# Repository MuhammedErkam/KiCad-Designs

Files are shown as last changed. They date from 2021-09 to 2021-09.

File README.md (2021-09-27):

# KiCad-Designs
My KiCad PCB Designs

This PCB is 4 layer PCB.
Signal - GND - POWER - Signal

##### MCU - STM32F103C8T6
##### RF Module - Ai Thinker Lora Ra-02 (SX1278)
##### IMU Sensor - MPU6050
##### TEMP-PRESS Sesnor - BMP280

##### This system works with USB Micro-B
Also Micro-B connector stands for USART with CH340E

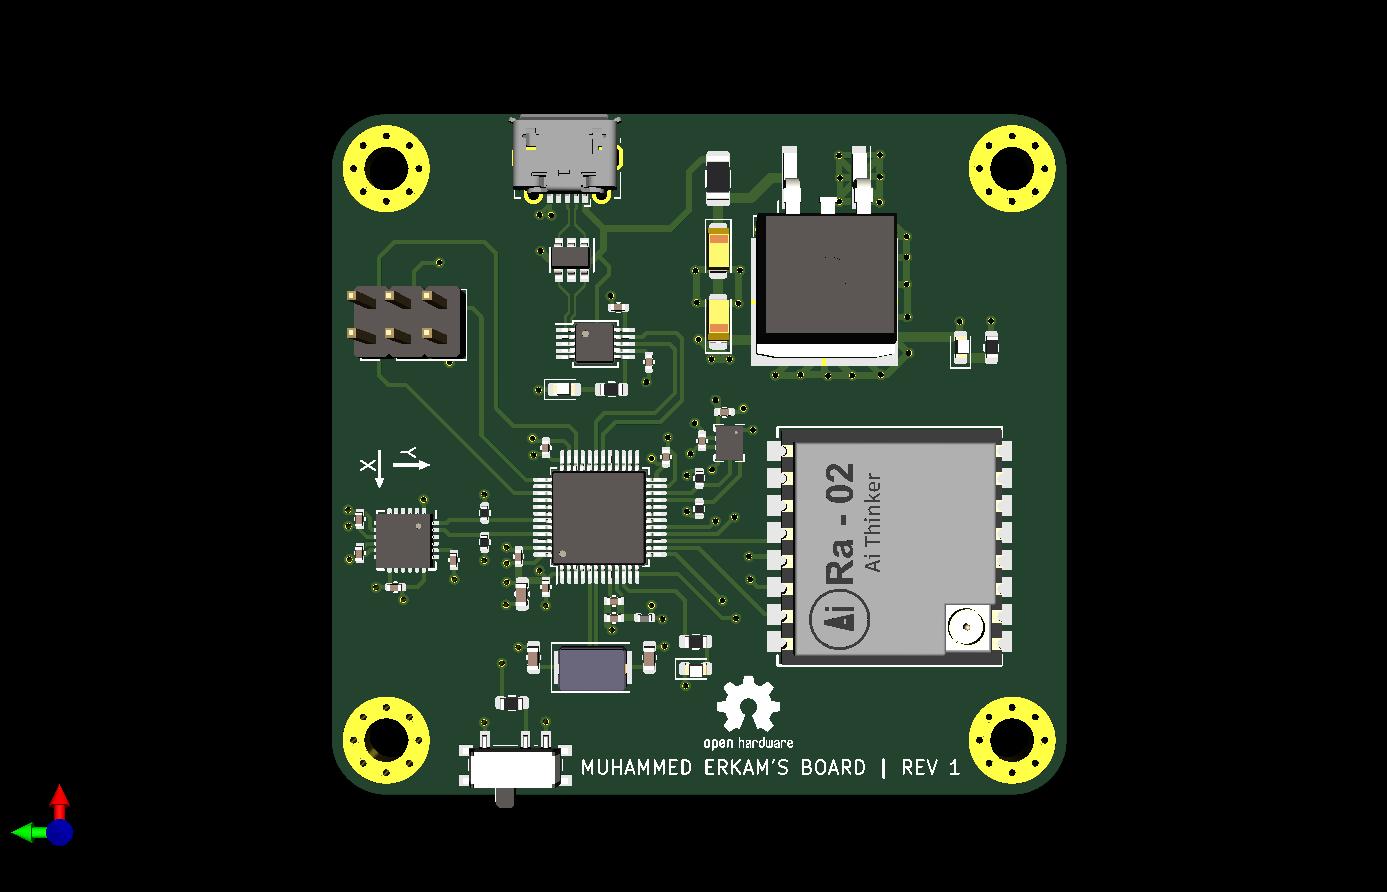
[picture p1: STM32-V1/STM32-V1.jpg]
PCB Photo


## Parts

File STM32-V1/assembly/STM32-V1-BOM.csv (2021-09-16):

Comment | Designator | Footprint | LCSC
10n | C10 | Capacitor_SMD:C_0402_1005Metric
2n2 | C15 | Capacitor_SMD:C_0402_1005Metric
30p | C16,C17 | Capacitor_SMD:C_0603_1608Metric
10u | C1,C2 | Capacitor_Tantalum_SMD:CP_EIA-3216-18_Kemet-A
4u7 | C3 | Capacitor_SMD:C_0603_1608Metric
100n | C4,C5,C6,C7,C11,C12,C13,C14,C18,C19 | Capacitor_SMD:C_0402_1005Metric
1u | C8 | Capacitor_SMD:C_0402_1005Metric
10u | C9 | Capacitor_SMD:C_0402_1005Metric
RED | D1,D3 | LED_SMD:LED_0603_1608Metric
BLUE | D2 | LED_SMD:LED_0603_1608Metric
JK-nSMD150-SF | F1 | Fuse:Fuse_1206_3216Metric
MountingHole_Pad | H1,H2,H3,H4 | MountingHole:MountingHole_3.2mm_M3_Pad_Via
USB_B_Micro | J1 | Connector_USB:USB_Micro-B_Molex-105017-0001
Conn_02x03_Odd_Even | J2 | Connector_PinHeader_2.54mm:PinHeader_2x03_P2.54mm_Vertical
27n | L1 | Inductor_SMD:L_0402_1005Metric
10k | R2 | Resistor_SMD:R_0603_1608Metric
1.5k | R3 | Resistor_SMD:R_0603_1608Metric
2k2 | R4,R5,R7,R8 | Resistor_SMD:R_0402_1005Metric
1k | R1,R6 | Resistor_SMD:R_0603_1608Metric
SW_SPDT | SW1 | Button_Switch_SMD:SW_SPDT_PCM12
LD1086D2T33TR | U1 | Package_TO_SOT_SMD:TO-263-2
USBLC6-2SC6 | U2 | Package_TO_SOT_SMD:SOT-23-6
BMP280 | U3 | Package_LGA:Bosch_LGA-8_2x2.5mm_P0.65mm_ClockwisePinNumbering
Ai-Thinker-Ra-02 | U4 | RF_Module:Ai-Thinker-Ra-02-LoRa
MPU-6050 | U5 | Sensor_Motion:InvenSense_QFN-24_4x4mm_P0.5mm
STM32F103C8Tx | U6 | Package_QFP:LQFP-48_7x7mm_P0.5mm
CH340E | U7 | Package_SO:MSOP-10_3x3mm_P0.5mm
Crystal | Y1 | Crystal:Crystal_SMD_5032-2Pin_5.0x3.2mm

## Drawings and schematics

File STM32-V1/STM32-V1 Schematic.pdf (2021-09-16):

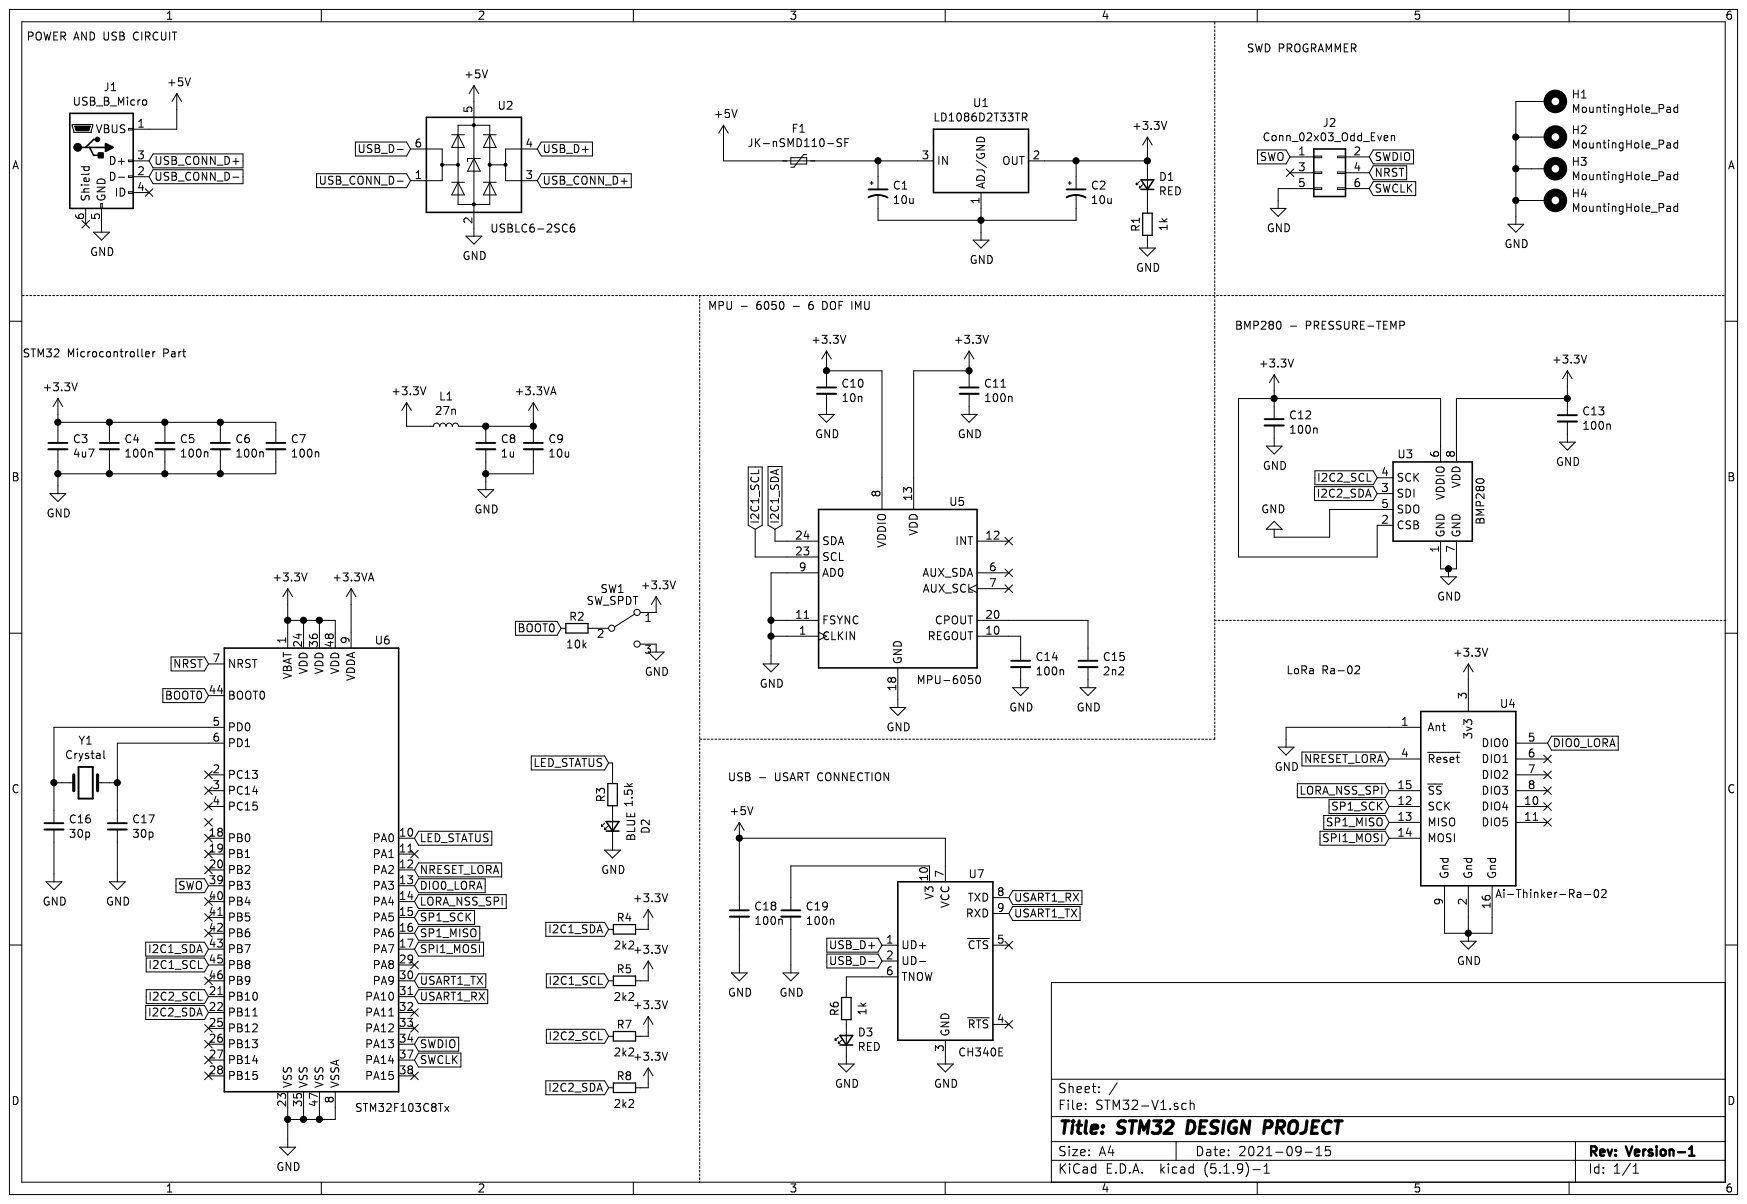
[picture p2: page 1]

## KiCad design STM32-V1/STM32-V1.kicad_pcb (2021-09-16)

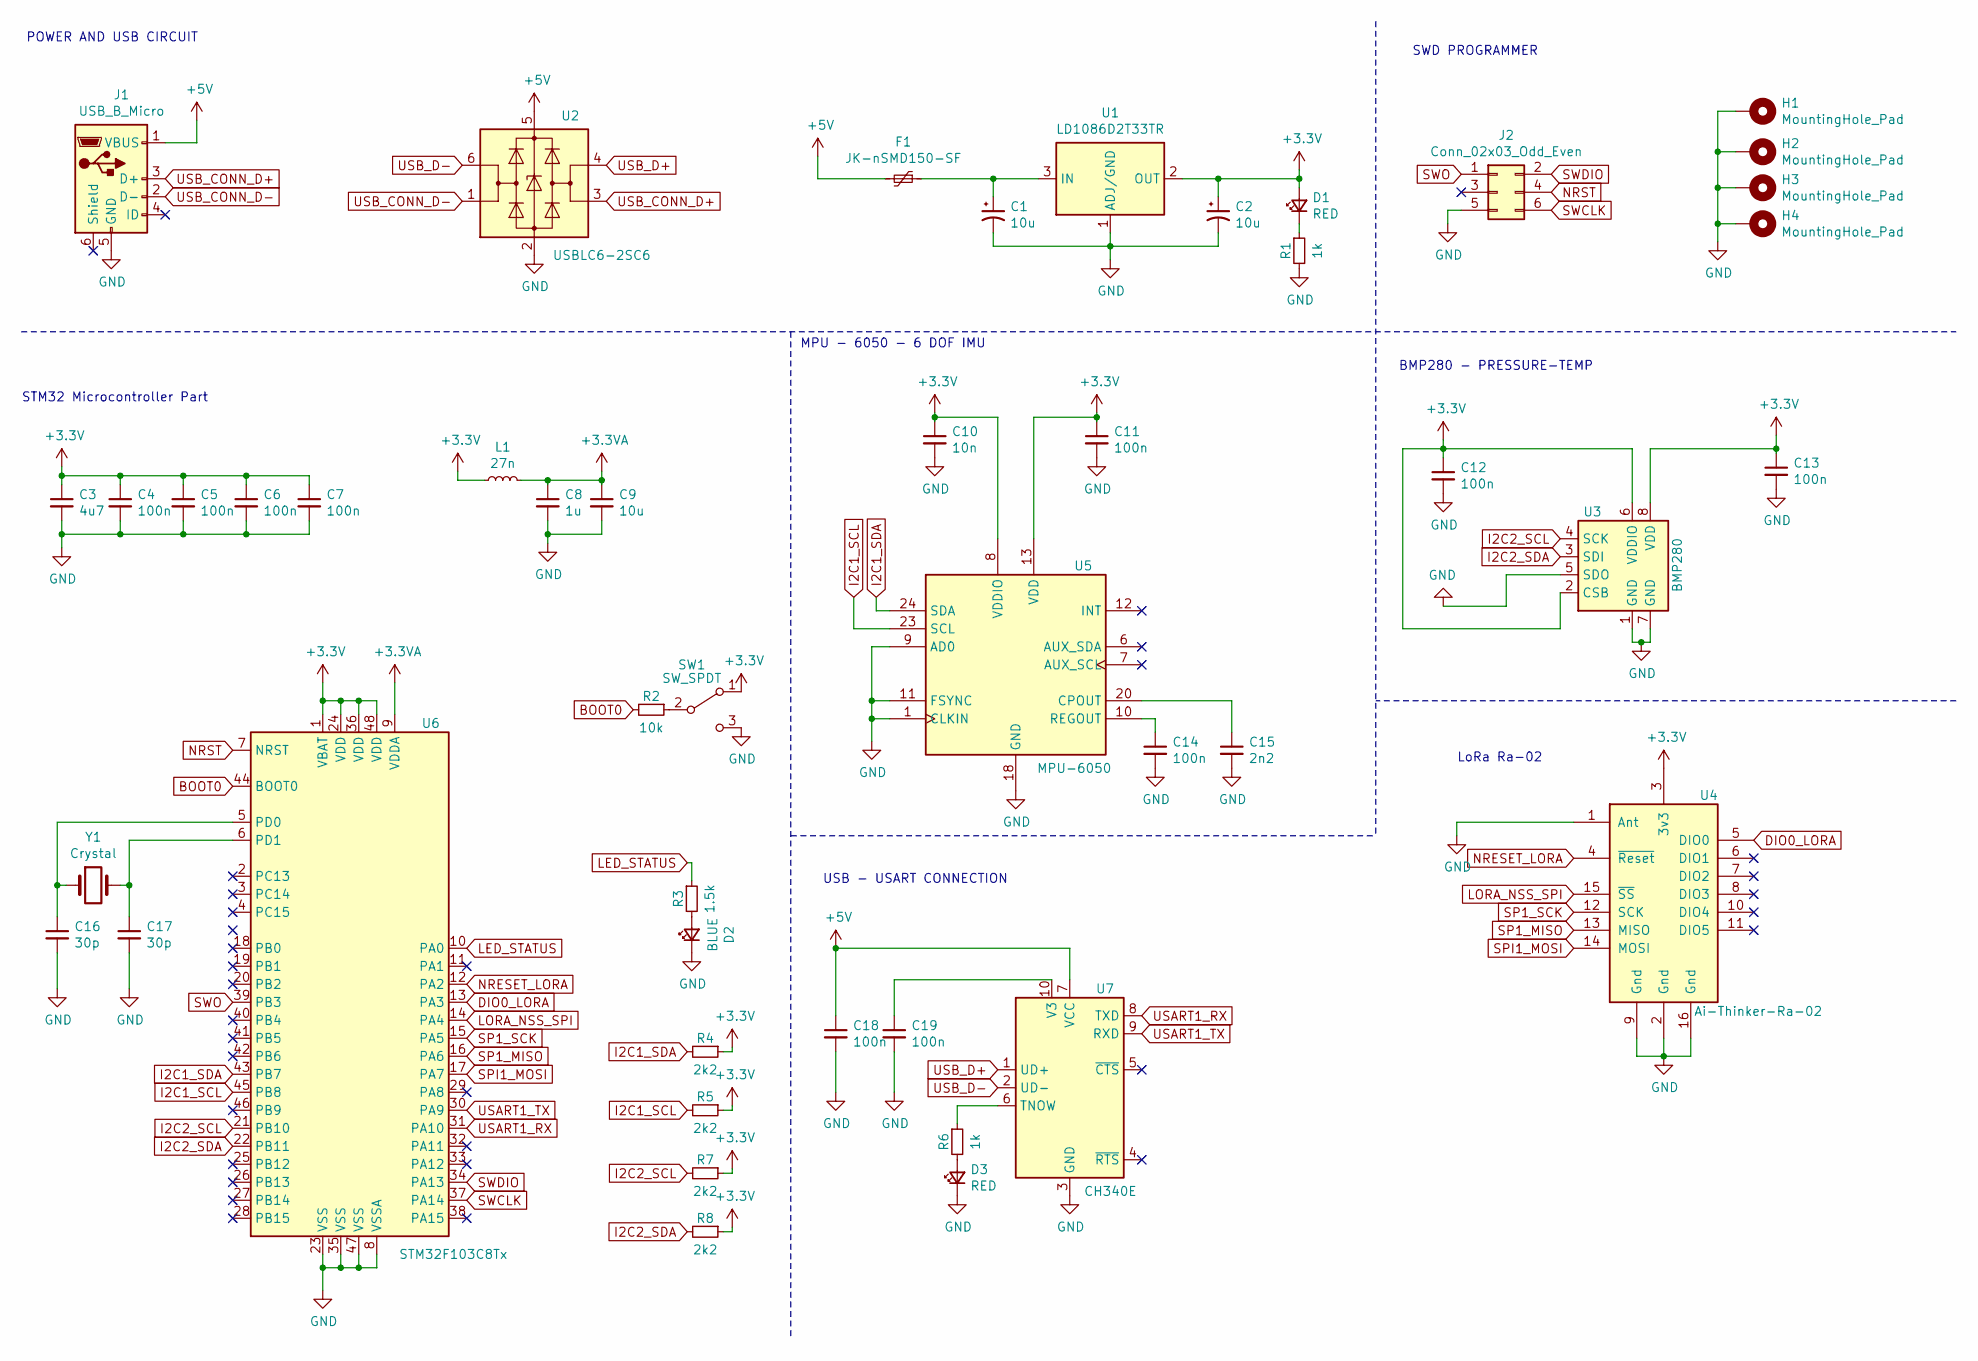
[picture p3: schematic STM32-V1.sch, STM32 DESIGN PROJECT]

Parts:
C1, C2: 10u; CP_EIA-3216-18_Kemet-A
C3: 4u7; C_0603_1608Metric
C4, C5, C6, C7, C11, C12, C13, C14, C18, C19: 100n; C_0402_1005Metric
C8: 1u; C_0402_1005Metric
C9: 10u; C_0402_1005Metric
C10: 10n; C_0402_1005Metric
C15: 2n2; C_0402_1005Metric
C16, C17: 30p; C_0603_1608Metric
D1, D3: RED; LED_0603_1608Metric
D2: BLUE; LED_0603_1608Metric
F1: JK-nSMD150-SF; Fuse_1206_3216Metric
H1, H2, H3, H4: MountingHole_Pad; MountingHole_3.2mm_M3_Pad_Via
J1: USB_B_Micro; USB_Micro-B_Molex-105017-0001
J2: Conn_02x03_Odd_Even; PinHeader_2x03_P2.54mm_Vertical
L1: 27n; L_0402_1005Metric
R1, R6: 1k; R_0603_1608Metric
R2: 10k; R_0603_1608Metric
R3: 1.5k; R_0603_1608Metric
R4, R5, R7, R8: 2k2; R_0402_1005Metric
SW1: SW_SPDT; SW_SPDT_PCM12
U1: LD1086D2T33TR; TO-263-2
U2: USBLC6-2SC6; SOT-23-6
U3: BMP280; Bosch_LGA-8_2x2.5mm_P0.65mm_ClockwisePinNumbering
U4: Ai-Thinker-Ra-02; Ai-Thinker-Ra-02-LoRa
U5: MPU-6050; InvenSense_QFN-24_4x4mm_P0.5mm
U6: STM32F103C8Tx; LQFP-48_7x7mm_P0.5mm
U7: CH340E; MSOP-10_3x3mm_P0.5mm
Y1: Crystal; Crystal_SMD_5032-2Pin_5.0x3.2mm

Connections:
+3.3VA: C8.1, C9.1, L1.2, U6.9 (VDDA)
+3V3: C2.1, C3.1, C4.1, C5.1, C6.1, C7.1, C10.1, C11.1, C12.1, C13.1, D1.2 (A), L1.1, R4.1, R5.1, R7.1, R8.1, SW1.1 (A), U1.2 (OUT), U3.2 (CSB), U3.6 (VDDIO), U3.8 (VDD), U4.3 (3v3), U5.8 (VDDIO), U5.13 (VDD), U6.1 (VBAT), U6.24 (VDD), U6.36 (VDD), U6.48 (VDD)
+5V: C18.1, F1.2, J1.1 (VBUS), U2.5 (VBUS), U7.7 (VCC)
BOOT0: R2.2, U6.44 (BOOT0)
DIO0_LORA: U4.5 (DIO0), U6.13 (PA3)
GND: C1.2, C2.2, C3.2, C4.2, C5.2, C6.2, C7.2, C8.2, C9.2, C10.2, C11.2, C12.2, C13.2, C14.2, C15.2, C16.2, C17.2, C18.2, C19.2, D2.1 (K), D3.1 (K), H1.1, H2.1, H3.1, H4.1, J1.5 (GND), J2.5, R1.2, SW1.3 (C), U1.1 (ADJ/GND), U2.2 (GND), U3.1 (GND), U3.5 (SDO), U3.7 (GND), U4.1 (Ant), U4.2 (Gnd), U4.9 (Gnd), U4.16 (Gnd), U5.1 (CLKIN), U5.9 (AD0), U5.11 (FSYNC), U5.18 (GND), U6.8 (VSSA), U6.23 (VSS), U6.35 (VSS), U6.47 (VSS), U7.3 (GND)
I2C1_SCL: R5.2, U5.23 (SCL), U6.45 (PB8)
I2C1_SDA: R4.2, U5.24 (SDA), U6.43 (PB7)
I2C2_SCL: R7.2, U3.4 (SCK), U6.21 (PB10)
I2C2_SDA: R8.2, U3.3 (SDI), U6.22 (PB11)
LED_STATUS: R3.1, U6.10 (PA0)
LORA_NSS_SPI: U4.15 (~SS), U6.14 (PA4)
NRESET_LORA: U4.4 (~Reset), U6.12 (PA2)
NRST: J2.4, U6.7 (NRST)
unnamed: C1.1, F1.1, U1.3 (IN)
unnamed: C14.1, U5.10 (REGOUT)
unnamed: C15.1, U5.20 (CPOUT)
unnamed: C16.1, U6.5 (PD0), Y1.1
unnamed: C17.1, U6.6 (PD1), Y1.2
unnamed: C19.1, U7.10 (V3)
unnamed: D1.1 (K), R1.1
unnamed: D2.2 (A), R3.2
unnamed: D3.2 (A), R6.2
unnamed: R2.1, SW1.2 (B)
unnamed: R6.1, U7.6 (TNOW)
SP1_MISO: U4.13 (MISO), U6.16 (PA6)
SP1_SCK: U4.12 (SCK), U6.15 (PA5)
SPI1_MOSI: U4.14 (MOSI), U6.17 (PA7)
SWCLK: J2.6, U6.37 (PA14)
SWDIO: J2.2, U6.34 (PA13)
SWO: J2.1, U6.39 (PB3)
USART1_RX: U6.31 (PA10), U7.8 (TXD)
USART1_TX: U6.30 (PA9), U7.9 (RXD)
USB_CONN_D+: J1.3 (D+), U2.3 (I/O2)
USB_CONN_D-: J1.2 (D-), U2.1 (I/O1)
USB_D+: U2.4 (I/O2), U7.1 (UD+)
USB_D-: U2.6 (I/O1), U7.2 (UD-)

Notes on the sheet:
STM32 Microcontroller Part
POWER AND USB CIRCUIT
BMP280 - PRESSURE-TEMP
MPU - 6050 - 6 DOF IMU
USB - USART CONNECTION
LoRa Ra-02
SWD PROGRAMMER

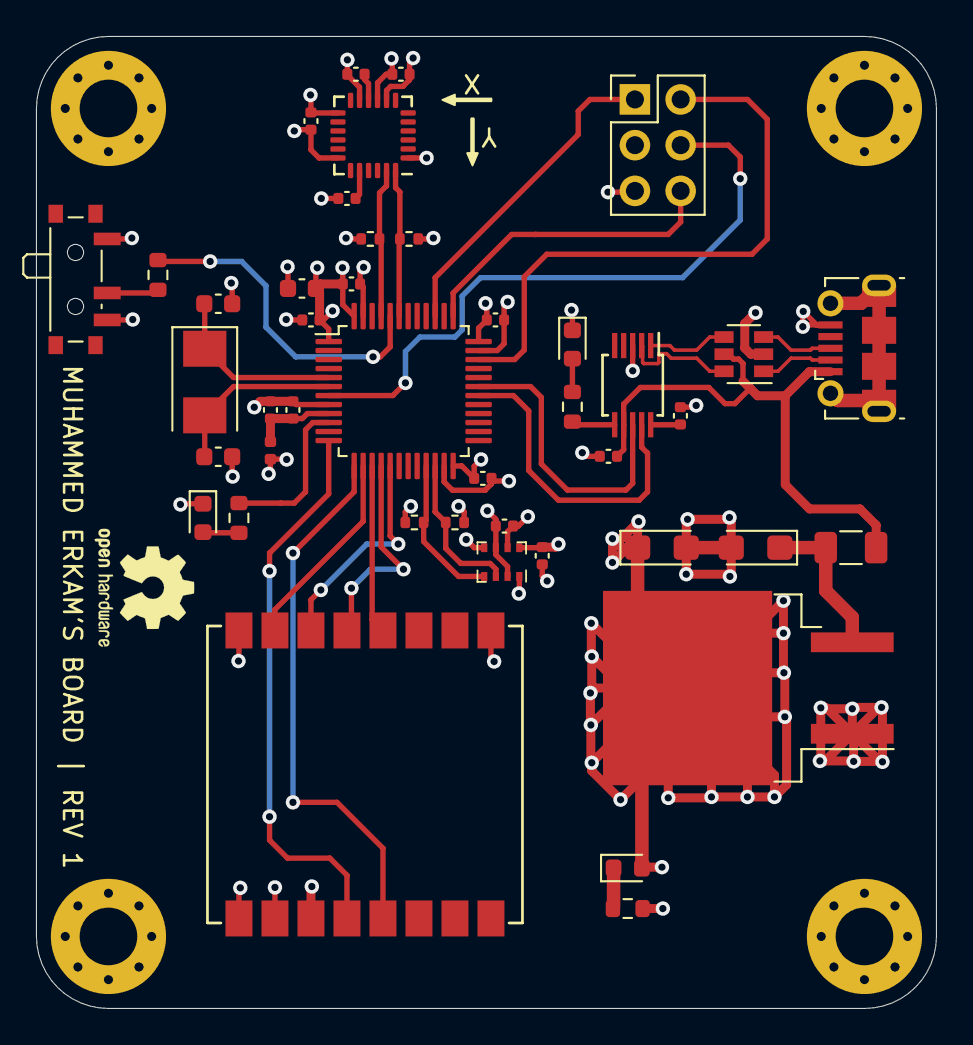
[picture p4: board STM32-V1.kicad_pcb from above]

Board: 4 copper layers, 50.0 x 54.0 mm, 47 parts (0 on the bottom side), 37 nets.

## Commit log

2021-09-16 BOM file is missing, I will add
    [STM32-V1-B_Cu.gbr, STM32-V1-B_Mask.gbr, STM32-V1-B_Paste.gbr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]
2021-09-16 My first KiCad Design, This is Rev 1
    [STM32-V1-BOM.csv, STM32-V1.kicad_pcb, STM32-V1.sch]
2021-09-27 PCB Photo is changed
